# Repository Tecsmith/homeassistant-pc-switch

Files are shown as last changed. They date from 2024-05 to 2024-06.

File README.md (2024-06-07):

#  HA PC Switch

**Automate power on your PC using [ESPHome](https://github.com/esphome/esphome) or [Tasmota](https://github.com/arendst/Tasmota), and integrated into [Home Assistant](https://www.home-assistant.io/).**

## About

For more, visit the project page here: https://tecsmith.github.io/homeassistant-pc-switch/

## Assets:

* [Schematic PDF](docs/ha-pc-switch-revB.pdf)

---

Made with &#x1F499; by [](https://github.com/vinorodrigues).

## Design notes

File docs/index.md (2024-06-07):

#  HA PC Switch

**Automate power on your PC using [ESPHome](https://github.com/esphome/esphome) or [Tasmota](https://github.com/arendst/Tasmota), and integrated into [Home Assistant](https://www.home-assistant.io/).**

---

**`STATUS`**: This project is in ideation stage.  Come back soon for progress.

**`LAST UPDATE`**: 7 June 2024

---

## Origins

Looking for a way to remotely start-up and shut-down a PC from Home Assistant.  Also need operational status (sensors) to drive automations.

### June 2024 progress

In a case of [Multiple Discovery](https://en.wikipedia.org/wiki/multiple_discovery), it turns out that this idea already has commercial solutions for sale. I've found a few variants on AliExpress:

1. [Computer Remote Switch,Wifi Smart PC Start Boot Card,Startup Card Work with Apple Homekit SIRI](https://www.aliexpress.com/item/1005005378143852.html) - *This one I really like and have bought myself, as it's written specifically for the Apple Homekit eco-system that I use.I also like that it uses the new ESPC2-12 module.*

2. [TISHRIC Wifi PC Power Switch Computer Remote Boot Startup Card Computer Restart Switch Timing Boot Device Work With Alexa Google](https://www.aliexpress.com/item/1005004861684220.html) - *I really like the PCI bracket plate of this one. Depends on Tuya though* :( *.*

3. [eWeLink Computer Remote Boot Card Remote Control Wireless WIFI Switch Relay Module For Computer Work with Google Home and Alexa](https://www.aliexpress.com/item/1005001727371911.html) - *I think this one is one of the first modules developed.  Also relies on Tuya though* :( *.*

**However** - none of the above are open source - so we don't have the ability to modify the firmware ... and to add to that, most rely on the Tuya eco-system - so not viable for off-line use, and adds the "cloud" factor to it's use.

So I'm progressing with building ... EE design is done, but I need to change focus to building the firmware.

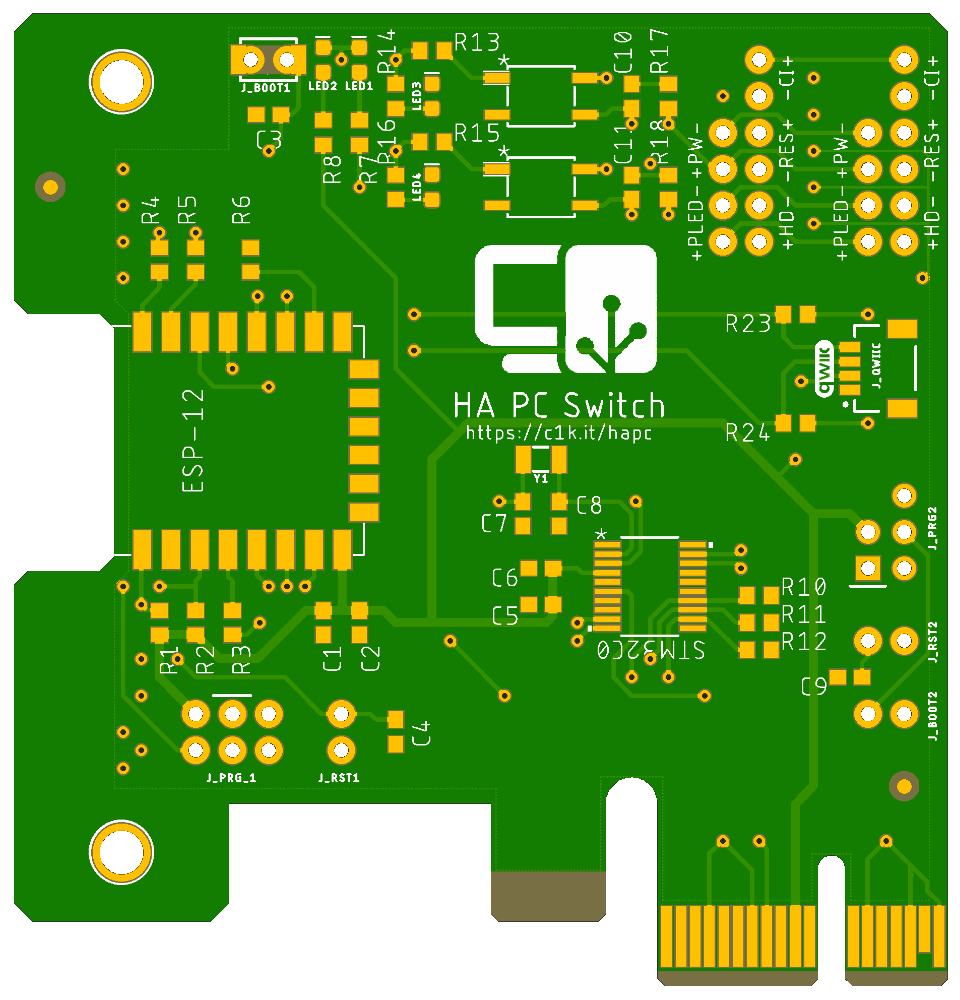
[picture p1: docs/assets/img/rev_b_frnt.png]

&nbsp;
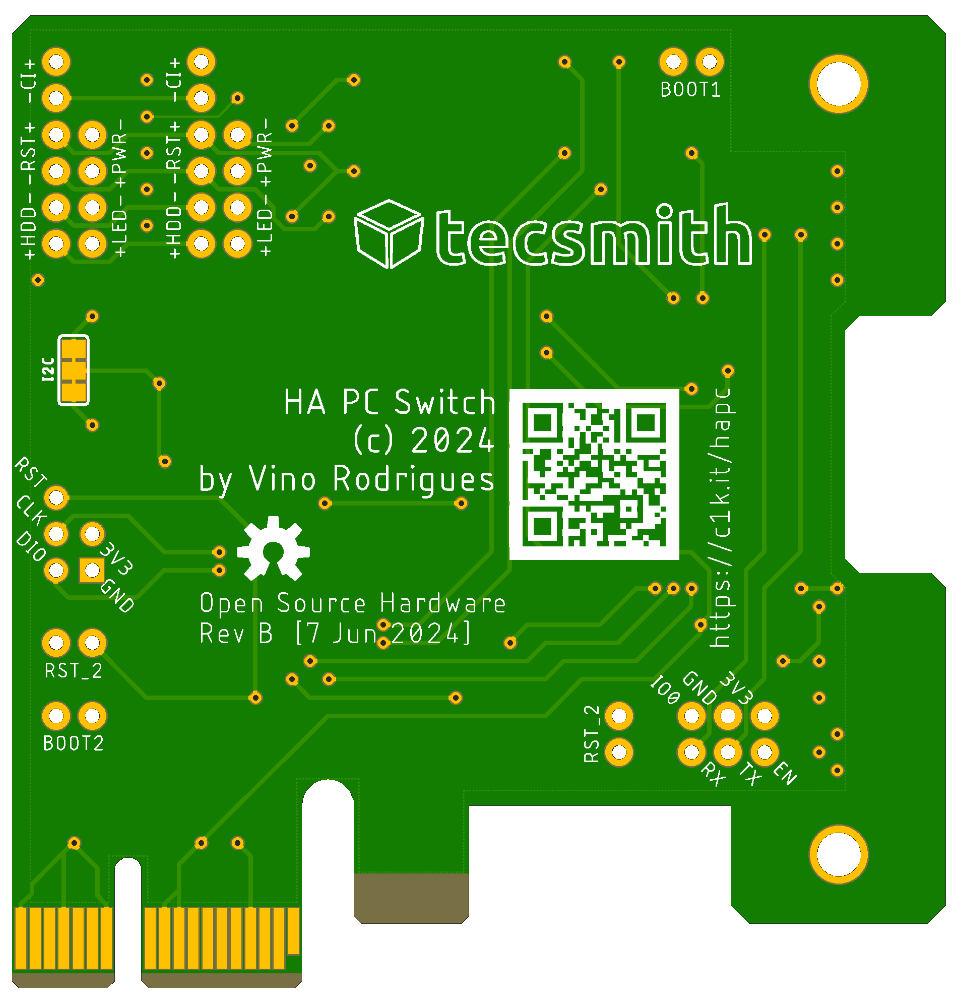
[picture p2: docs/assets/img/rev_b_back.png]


## Ideas

### Other People's Projects

* Zvonko Bockaj *@Hackster* - [WEMOS ESP8266 Remote PC Switch](https://www.hackster.io/zvonko-bockaj/wemos-esp8266-remote-pc-switch-062c7a) `// this one makes most sense`
* `ajfriesen` - [The pc-switch](https://www.ajfriesen.com/pc-switch/) `// great source for ESPHome YAML example`
* `Erriez` *@Github* - [ESPHomePCPowerControlHomeAssistant](https://github.com/Erriez/ESPHomePCPowerControlHomeAssistant/) `// ditto`

&

* `SilverFire` *@Github* - [esp8266-pc-power-control](https://github.com/SilverFire/esp8266-pc-power-control/)
* Lerk - [Turning a PC on and off using an ESP8266](https://lerks.blog/p/turning-a-pc-on-and-off-using-an-esp)

## Specifications (as a wish list)

### Inputs

1. ~~Power Standby (from PSU pin 9 {purple} / +5V SB (Standby)) - *as source of operating +5V power*~~
2. ~~Power Good (from PSU, pin 8 {grey} / PG (Pwr Good))~~
3. ~~Power Supply ON (from PSU, pins 21,22 {red} )~~
4. ~~PC ON (from Case LED)~~
5. ~~Case / MLB POWER Button~~
6. ~~Case / MLB Reset Button~~

* ~~GND (2x sources from PSU & MLB)~~

[June '24 update] - dropping the need for inputs.  Only one is needed at this stage .. i.e. is the PC ON or not.  Also removing the need for PSU monitoring, **and** it's source of power.  Turns out that PCIe bus supplies a 3.3V "Aux" line (a.k.a. "Standby" power), so we can just tap of the PCIe slot.

### Sensors (exposed to HA)

* ~~Power Good (from PSU, pin 8 {grey, *measure `true` when +5V*})~~
* ~~Power (Supply) ON (from PSU, pin 16 {green, *measure `false` when +5V* } / PS-ON (Pwr Sply switch))~~
    * ~~*This is the pin that need to be grounded for the PSU to switch on, so needs careful testing to make sure one does not have false ON states.*~~
* ~~(PC) Power ON (from MLB, case LED) {*measure `true` when +5V*}~~
* ~~Optional: via D1 Mini hats~~
    * ~~*(e.g. Case temperature)*~~
    * ~~expose D1 and D2 pins ...~~
    * ~~... or as I2C bus~~

### Outputs
* Power "relay" *(See note about "relay"'s in ideas below)*
* Reset "relay"
* ~~Case LED (as passthrough)~~
* ~~Optional: via D1 Mini hats~~
    ~~*(e.g. Contact Relay, as power to RGB LED's switch)*~~

[June '24 Update] - Solid state / MOSFET relays are still in.  Addon outputs are however dropped.  But... I2C is exposed as a single QWICC connector in case one wants to extend.

##### Terms used above
* **PSU** = Power Supply (Unit) <br/>
* **MLB** = Mail (Logic) Board / PC Motherboard 

## Ideas

* ~~"Sensor" should be isolated from circuit with an Op-amp Comparator](https://www.electronics-tutorials.ws/opamp/op-amp-comparator.html) or [Level Shifter](https://www.sparkfun.com/products/12009) circuit.  *(Inputs will be 5V, whilst the ESPxx works on 3.3v.)*~~

* "Relay" should be an [Optocoupler](https://www.electronics-tutorials.ws/blog/optocoupler.html)
    * ~~Do **<u>not</u>** use a transistor, nor a mechanical relay~~

    * Some PC's have "Positive" switches, others have "Negative" switches.  Accounting for this is too complex *(i.e. prone to installer error)*, so would it be better to use a ~~*relay* *(e.g. Omron G6K [SMD @ &#xB1;$7], or Songle `SRD-3VDC-SL-C` / Omrom G5LE [THD @ &#xB1;$0.36&#xA2;] )*~~.

        The issue here is that the MLB *(PC Motherboard)* may be using a low-sensing circuit, or a high-sensing circuit - and this PCB must account for both!

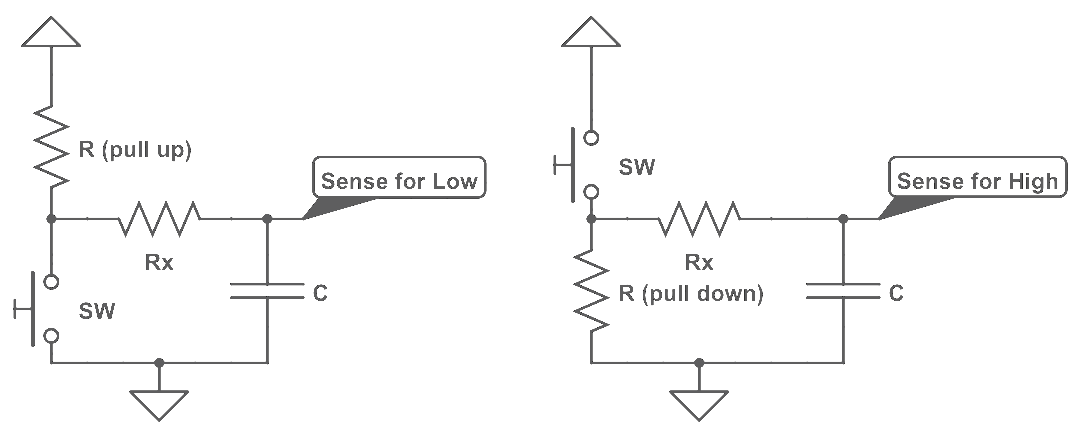
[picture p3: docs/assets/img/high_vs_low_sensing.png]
        <br/>

        All we get access to is the points that are the pins of the switch.

    * Solution looks to be a TIP3123 opto-MOSFET, thanks to [Andy aka](https://electronics.stackexchange.com/questions/548380/how-is-it-possible-to-replace-a-relay-with-transistors).

* &#x26A0; "Relay" should be driven by a "Delay OFF type" circuit, and 2 timings must be provided
    * 300ms delay from ON back to OFF to simulate a "press".
    * 5.5s delay on ON, then back to OFF to simulate a "long press".

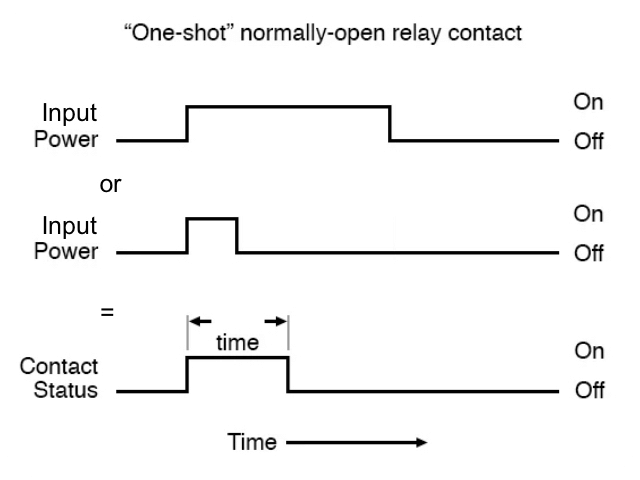
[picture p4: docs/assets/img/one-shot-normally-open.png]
        <br/>

    3 possible ways to do this:

    1. EE solution with caps and transistors - *not really viable since because of its variable performance and unchangeable nature. (See [here](https://www.homemade-circuits.com/simple-delay-timer-circuits-explained/))*

    2. If Software solution (i.e. on ESPHome or Tasmota), then how do we create a **"One-Shot" Normally-Open** switch?

        * ESPHome, can do this with with a [`on_turn_on` trigger](https://esphome.io/components/switch/gpio.html#momentary-switch).
        
        * Tasmota, can do this with "*Rules*" on the device.

        * Home Assistant with an automation trigger using an "`action`" > "`sequence`".

        But, what if the user forgets to "modify" the default f/w or build the HA automation required?  The device ***<u>must</u>*** handle the one-shot functionally itself.

        &#x26A0; Custom f/w (or fork of) must be built for timed "one-shot" / "delay off" functionality.

    3. Usa a second MCU with a timing circuit - e.g. ~~ATtiny85 or **STM8S001J3**~~ or **STM32C0**.

        * May be useful as a feedback "sensor".
        * Don't forget to provide programming headers.

* ~~Tap into the PSU ATX Cable for power and PSU inputs~~
    * ~~Std ATX~~ <br/>
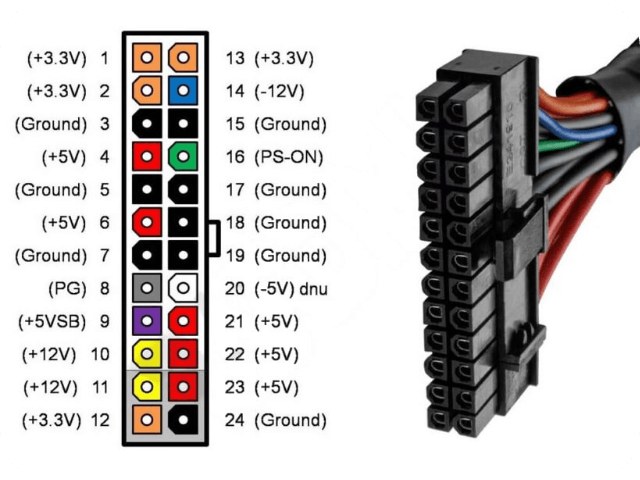
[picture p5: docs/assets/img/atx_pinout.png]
        
    * ~~Use a ATX power extender to "tap" into correct cables~~ <br/>
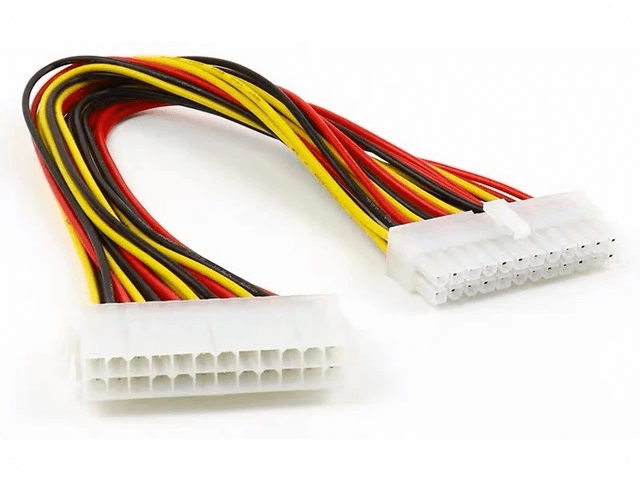
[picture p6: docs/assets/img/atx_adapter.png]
        

* ~~Use the WEMOS D1 Mini form-factor and pin-outs, but prototype on:~~
    * ~~[WEMOS D1 Mini Pro](https://www.aliexpress.com/item/1005006109635545.html) (with external antenna) <br/>~~
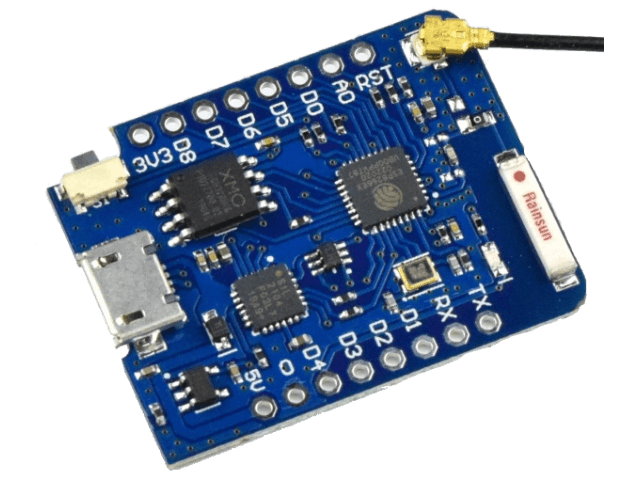
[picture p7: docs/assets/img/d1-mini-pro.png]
      
    * ~~[LOLIN ESP32 S2 Mini](https://www.aliexpress.com/item/1005006157693055.html)~~ <br/>
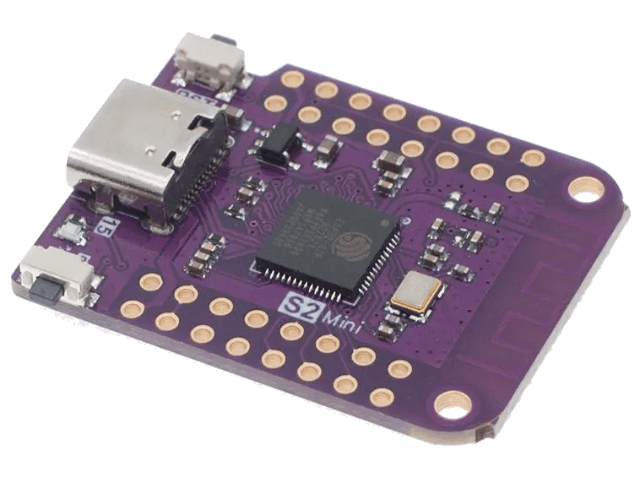
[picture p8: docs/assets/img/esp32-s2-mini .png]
      

* [May '24 Update] ~~Also add a~~ footprint for the **ESP-12F**/ESP-12S module
    * Cheaper, but needs external programmer (add headers for that).

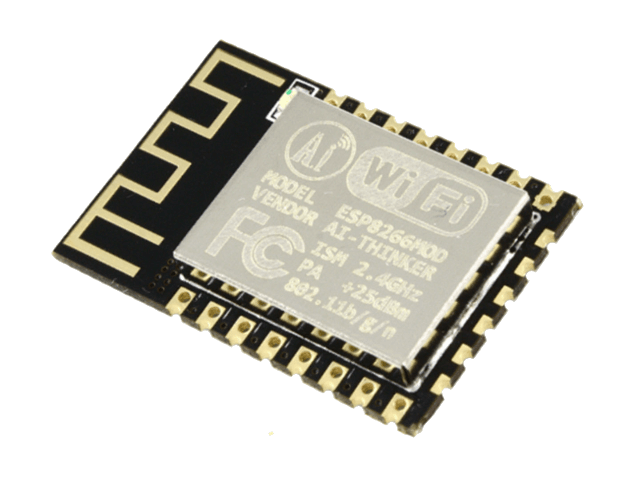
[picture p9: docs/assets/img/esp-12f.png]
      

    * [Update '24 Update] Both the **ESP-07** and the newer **ESPC2-12** modules have the same footprint and pinout, adding far more versatility.

* ~~Build the PCB in a way that the unit can attach to a **PCI Slot Bracket Cover**, specifically build for:~~
    * ~~PCI Slot Fan Mount Rack for video card for 90mm and 120mm fans~~ <br/>
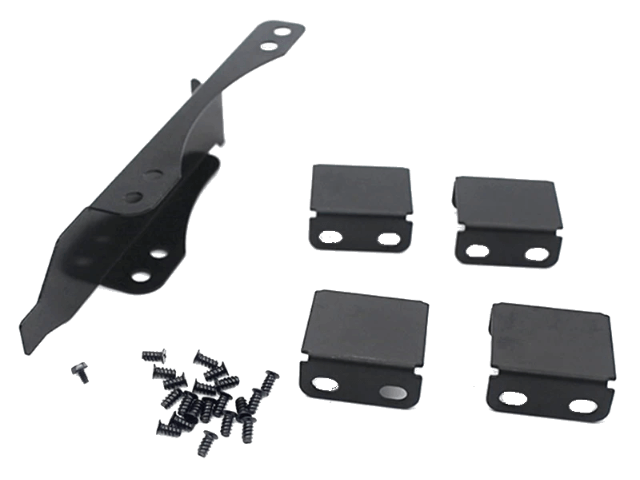
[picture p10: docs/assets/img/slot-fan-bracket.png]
      
    * ~~PCI Slot for 2.5inch hard drive, rear panel mount~~ <br/>
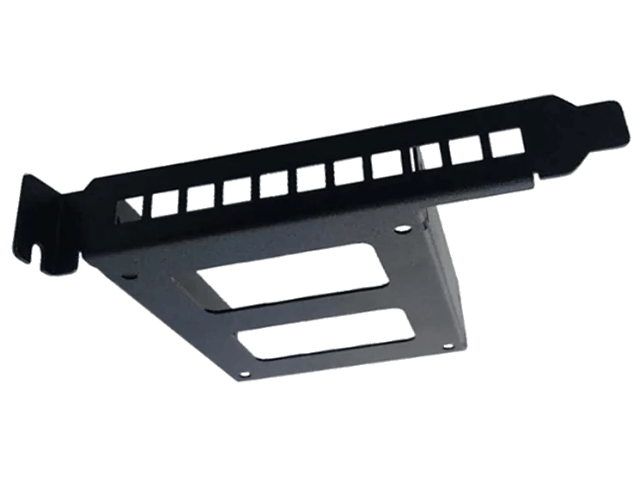
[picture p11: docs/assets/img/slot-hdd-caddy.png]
      

    Will allow for drilling holes for external antenna.

* [June '24 Update] Build to [PCIe V2 specification](specs/pci-express-card-electromechanical-specification-revision-2.pdf).  To fit standard PCI Bracket plates:
  
  * [Example 1](https://www.aliexpress.com/item/1005005341638856.html)
  * [Example 2](https://www.aliexpress.com/item/1005004003916975.html)

---

Made with &#x1F499; by [](https://github.com/vinorodrigues).

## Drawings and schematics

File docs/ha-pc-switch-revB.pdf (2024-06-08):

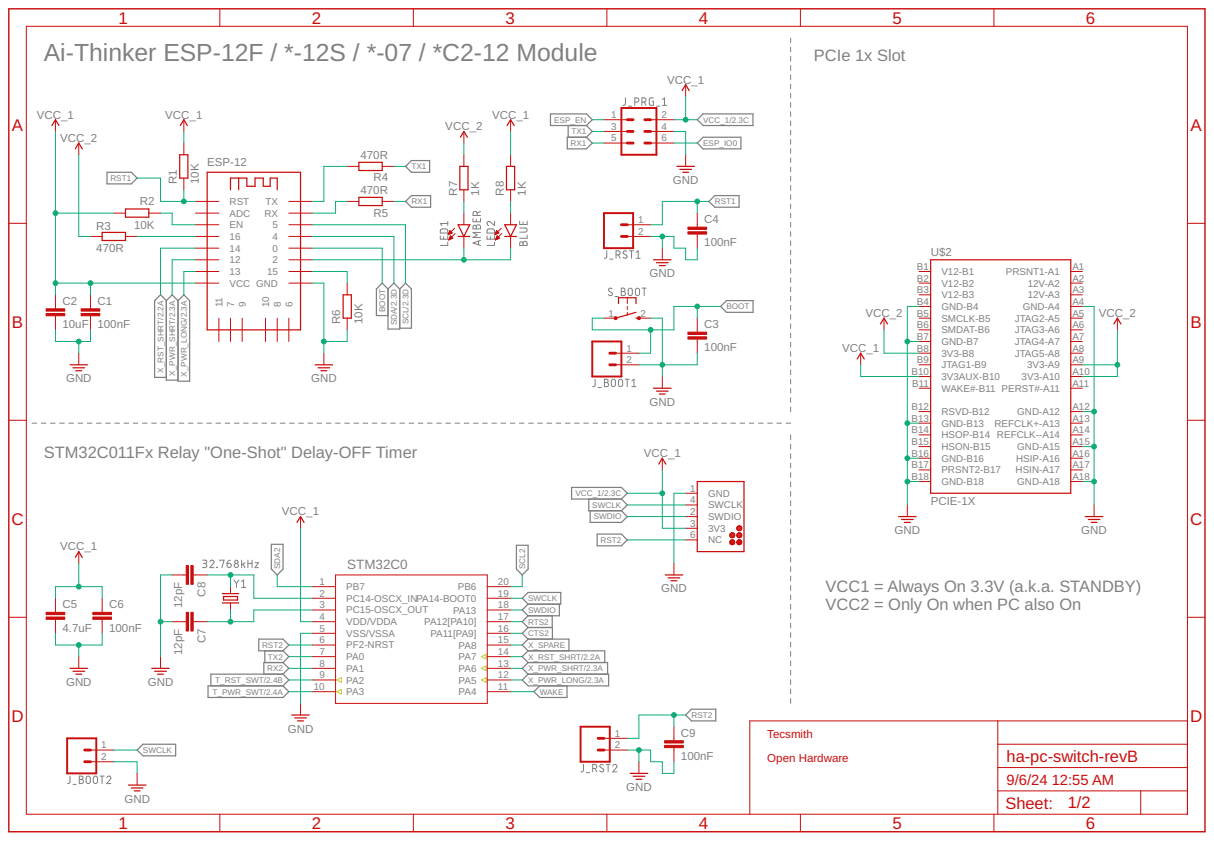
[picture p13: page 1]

Ai-Thinker ESP-12F / *-12S / *-07 / *C2-12 Module

STM32C011Fx Relay "One-Shot" Delay-OFF Timer

VCC1 = Always On 3.3V (a.k.a. STANDBY)
VCC2 = Only On when PC also On

2 | | 19 PB6
3 | | 18 PA14-BOOT0
4 | | 15 PA11[PA9] 16 PA12[PA10] 17 PA13

7 | 14 PA8
8 | 13 PA7
9 | 12 PA6

ha-pc-switch-revB
Sheet:

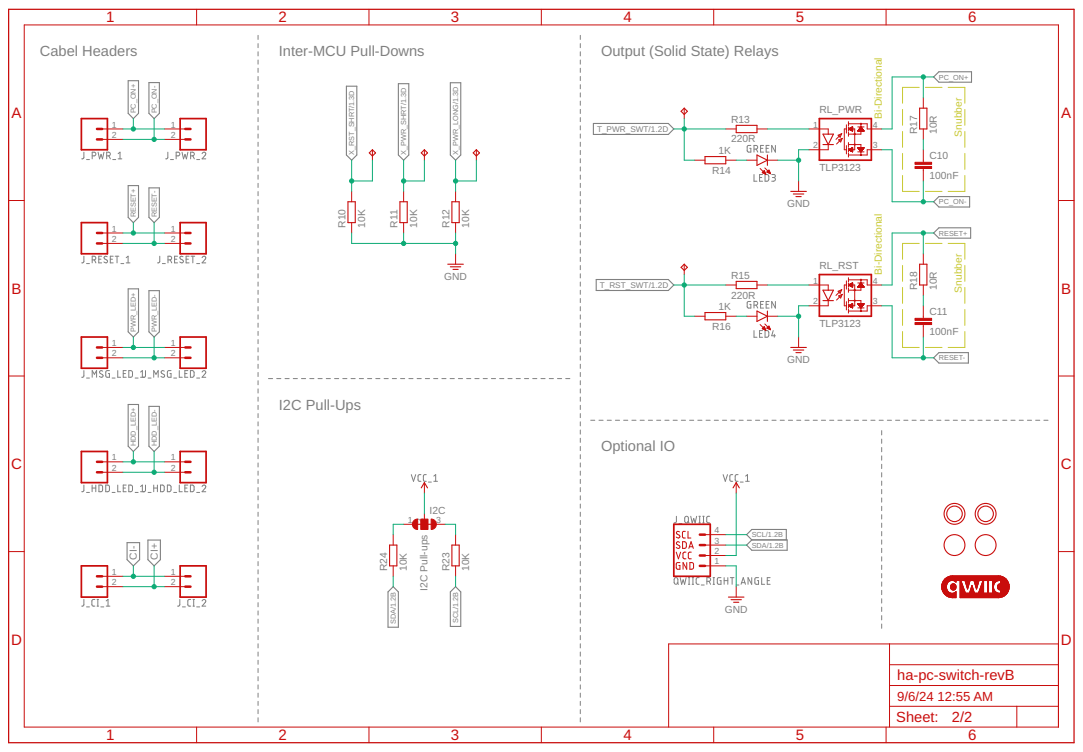
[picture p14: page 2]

Snubber Snubber Bi-Directional Bi-Directiona Cabe l l Headers Output (Solid State) Relays Optional IO I2C Pull-ups Inter-MCU Pull-Downs I2C Pull-Ups 100nF 10R 220R GND 100nF 10R 220R GND GND TLP3123 TLP3123 1K1K 10K 10K 10K 10K 10K GND 12121212 12121212 12 12 C10 R1R13 7 C11 R1R15 8 1234 12 34 RL_PWR 12 34 RL_RST R14 R16 1 23 I2C R23 R24 R11 R12 R10 PWR_LED+ RESET+ RESET+ PC_ON+ PC_ON+ HDD_LED+ PWR_LED- HDD_LED- PC_ON- PC_ON- RESET- RESET- CI- CI+ T_PWR_SWT/1.2D T_RST_SWT/1.2D SCL/1.2B SCL/1.2B SDA/1.2B SDA/1.2B X_PWR_SHRT/1.3D X_PWR_LONG/1.3D X_RST_SHRT/1.3D Sheet: ABCD 1 2 3 4 5 6 ABCD 1 2 3 4 5 6 ha-pc-switch-revB 9/6/24 12:55 AM 2/2

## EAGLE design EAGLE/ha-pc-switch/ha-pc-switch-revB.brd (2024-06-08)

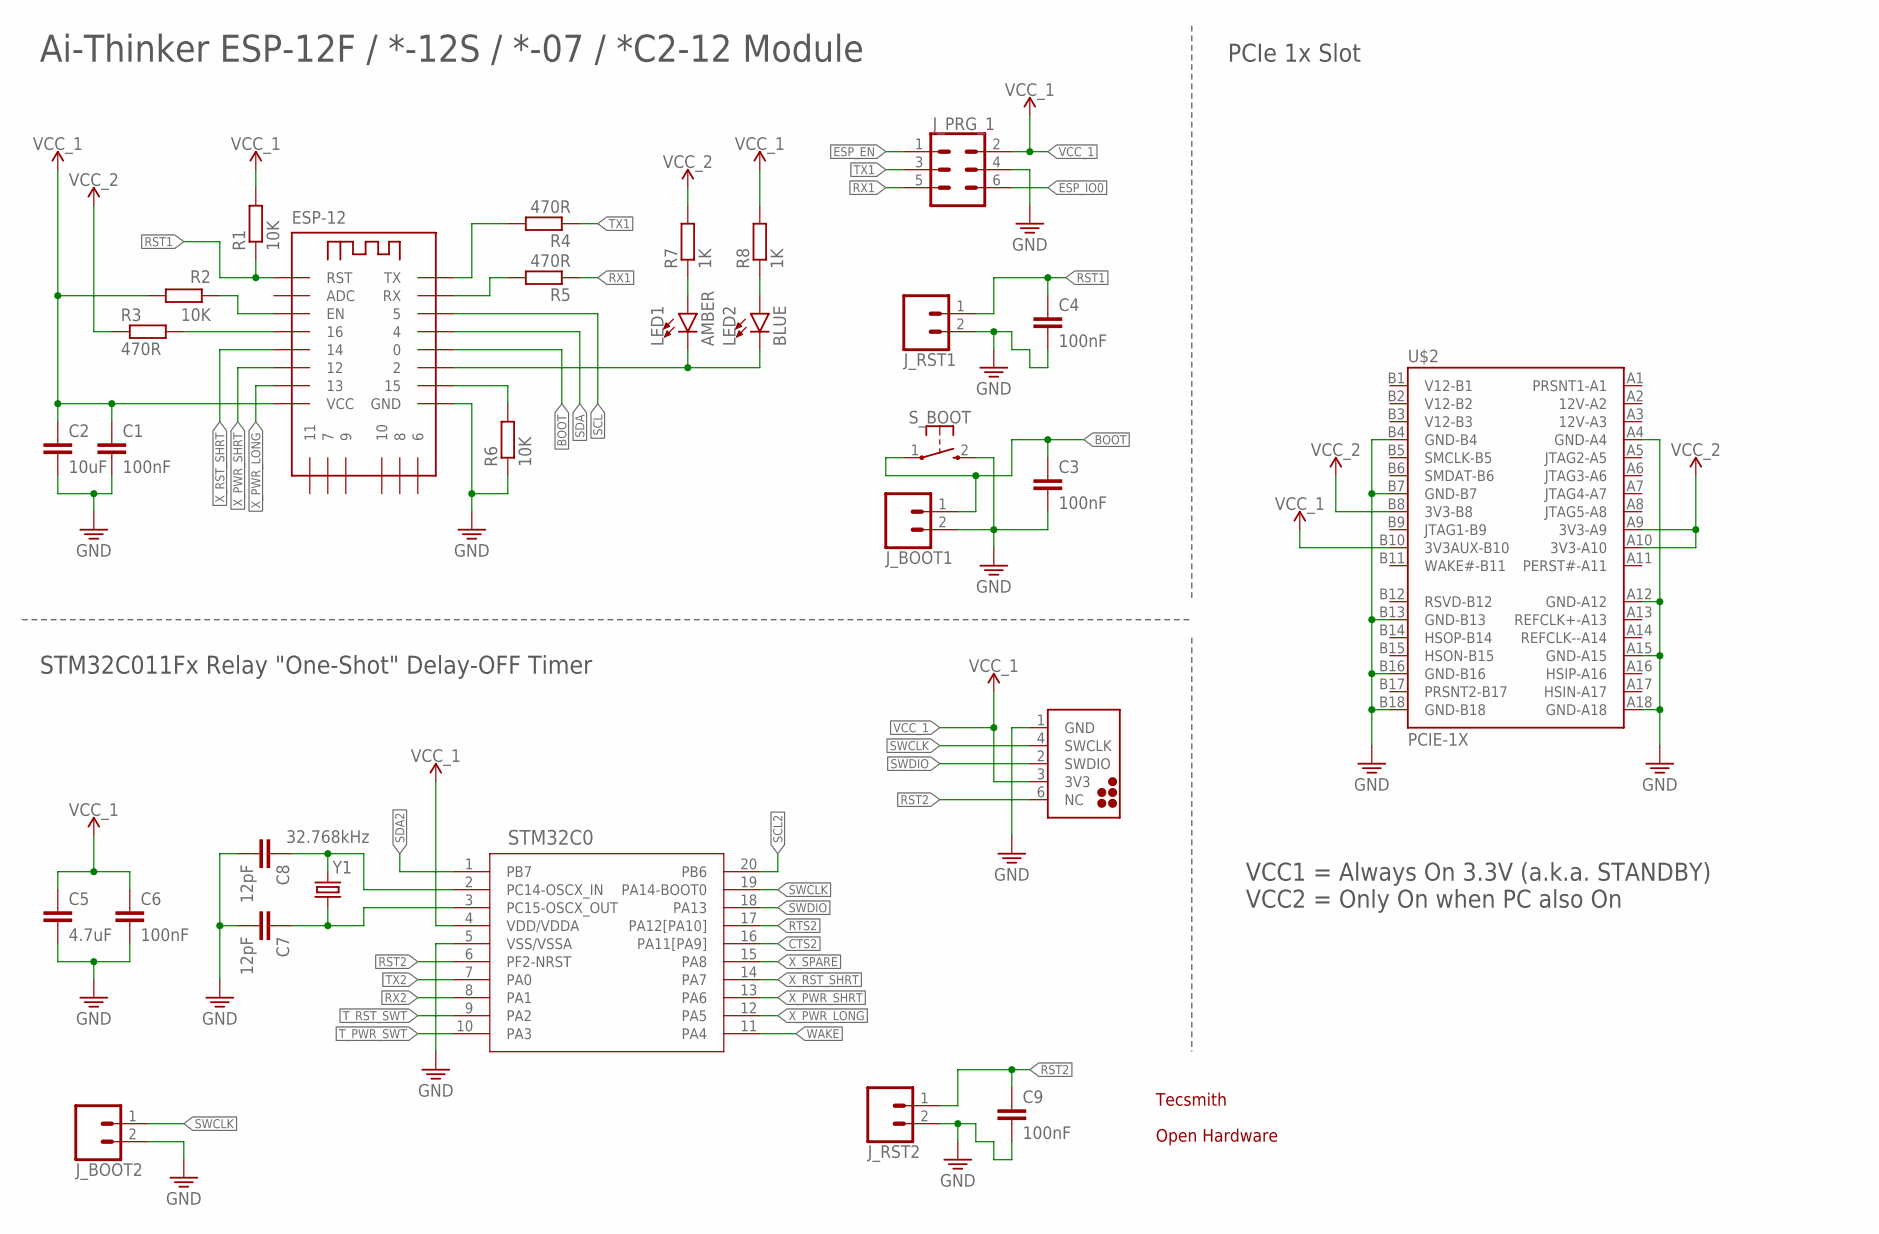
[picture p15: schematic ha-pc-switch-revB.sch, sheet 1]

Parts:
C1, C3, C4, C6, C9: 100nF; C0603
C2: 10uF; C0603
C5: 4.7uF; C0603
C7, C8: 12pF; C0603
ESP-12: ESPRESSIF-ESP-12F&ESMD; ESP8266-ESP-12E
J_BOOT1, J_BOOT2: CONN_021X02_NO_SILK; 1X02_NO_SILK
J_PRG2: NUCLEO_HEADER; NUCLEO
J_PRG_1: CONN_03X2NO_SILK; 2X3-NS
J_RST1, J_RST2: CONN_021X02_NO_SILK; 1X02_NO_SILK
LED1: AMBER; LED-0603
LED2: BLUE; LED-0603
LOGO1: OSHW-LOGOM; OSHW-LOGO-M
R1, R2, R6: 10K; R0603
R3, R4, R5: 470R; R0603
R7, R8: 1K; R0603
STM32C0: STM32C011FTSSOP20_STM-M; TSSOP20-M
S_BOOT: MOMENTARY-SWITCH-SPST-1; SKRKAEE020
U$1: TECSMITH-LOGOLONG; TECSMITH-NAME
U$2: PCIE-1X
Y1: 32.768kHz; CRYSTAL-SMD-3.2X1.5MM

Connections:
BOOT: C3.1, ESP-12.GPIO0 (0), J_BOOT1.1, S_BOOT.1
CTS2: STM32C0.16 (PA11[PA9])
ESP_EN: ESP-12.EN, J_PRG_1.1, R2.2
ESP_IO0: J_PRG_1.6
GND: C1.2, C2.2, C3.2, C4.2, C5.2, C6.2, C7.2, C8.2, C9.2, ESP-12.GND, J_BOOT1.2, J_BOOT2.2, J_PRG2.1 (GND), J_PRG_1.4, J_RST1.2, J_RST2.2, R6.1, STM32C0.5 (VSS/VSSA), S_BOOT.2 (3), U$2.A4 (GND-A4), U$2.A12 (GND-A12), U$2.A15 (GND-A15), U$2.A18 (GND-A18), U$2.B4 (GND-B4), U$2.B7 (GND-B7), U$2.B13 (GND-B13), U$2.B16 (GND-B16), U$2.B18 (GND-B18); also elsewhere on the board
unnamed: ESP-12.GPIO16 (16), R3.2
unnamed: LED2.A, R8.1
unnamed: C8.1, STM32C0.2 (PC14-OSCX_IN), Y1.P$2 (2)
unnamed: C7.1, STM32C0.3 (PC15-OSCX_OUT), Y1.P$1 (1)
unnamed: LED1.A, R7.1
unnamed: ESP-12.RXD0 (RX), R5.2
unnamed: ESP-12.GPIO2 (2), LED1.C, LED2.C
unnamed: ESP-12.TXD0 (TX), R4.2
unnamed: ESP-12.GPIO15 (15), R6.2
RST1: C4.1, ESP-12.RST, J_RST1.1, R1.1
RST2: C9.1, J_PRG2.6 (NC), J_RST2.1, STM32C0.6 (PF2-NRST)
RTS2: STM32C0.17 (PA12[PA10])
RX1: J_PRG_1.5, R5.1
RX2: STM32C0.8 (PA1)
SCL: ESP-12.GPIO5 (5); also elsewhere on the board
SCL2: STM32C0.20 (PB6)
SDA: ESP-12.GPIO4 (4); also elsewhere on the board
SDA2: STM32C0.1 (PB7)
SWCLK: J_BOOT2.1, J_PRG2.4 (SWCLK), STM32C0.19 (PA14-BOOT0)
SWDIO: J_PRG2.2 (SWDIO), STM32C0.18 (PA13)
TX1: J_PRG_1.3, R4.1
TX2: STM32C0.7 (PA0)
T_PWR_SWT: STM32C0.10 (PA3); also elsewhere on the board
T_RST_SWT: STM32C0.9 (PA2); also elsewhere on the board
VCC_1: C1.1, C2.1, C5.1, C6.1, ESP-12.VCC, J_PRG2.3 (3V3), J_PRG_1.2, R1.2, R2.1, R8.2, STM32C0.4 (VDD/VDDA), U$2.B10 (3V3AUX-B10); also elsewhere on the board
VCC_2: R3.1, R7.2, U$2.A9 (3V3-A9), U$2.A10 (3V3-A10), U$2.B8 (3V3-B8)
WAKE: STM32C0.11 (PA4)
X_PWR_LONG: ESP-12.GPIO13 (13), STM32C0.12 (PA5); also elsewhere on the board
X_PWR_SHRT: ESP-12.GPIO12 (12), STM32C0.13 (PA6); also elsewhere on the board
X_RST_SHRT: ESP-12.GPIO14 (14), STM32C0.14 (PA7); also elsewhere on the board
X_SPARE: STM32C0.15 (PA8)

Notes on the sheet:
Ai-Thinker ESP-12F / *-12S / *-07 / *C2-12 Module
STM32C011Fx Relay "One-Shot" Delay-OFF Timer
VCC1 = Always On 3.3V (a.k.a. STANDBY) VCC2 = Only On when PC also On
PCIe 1x Slot

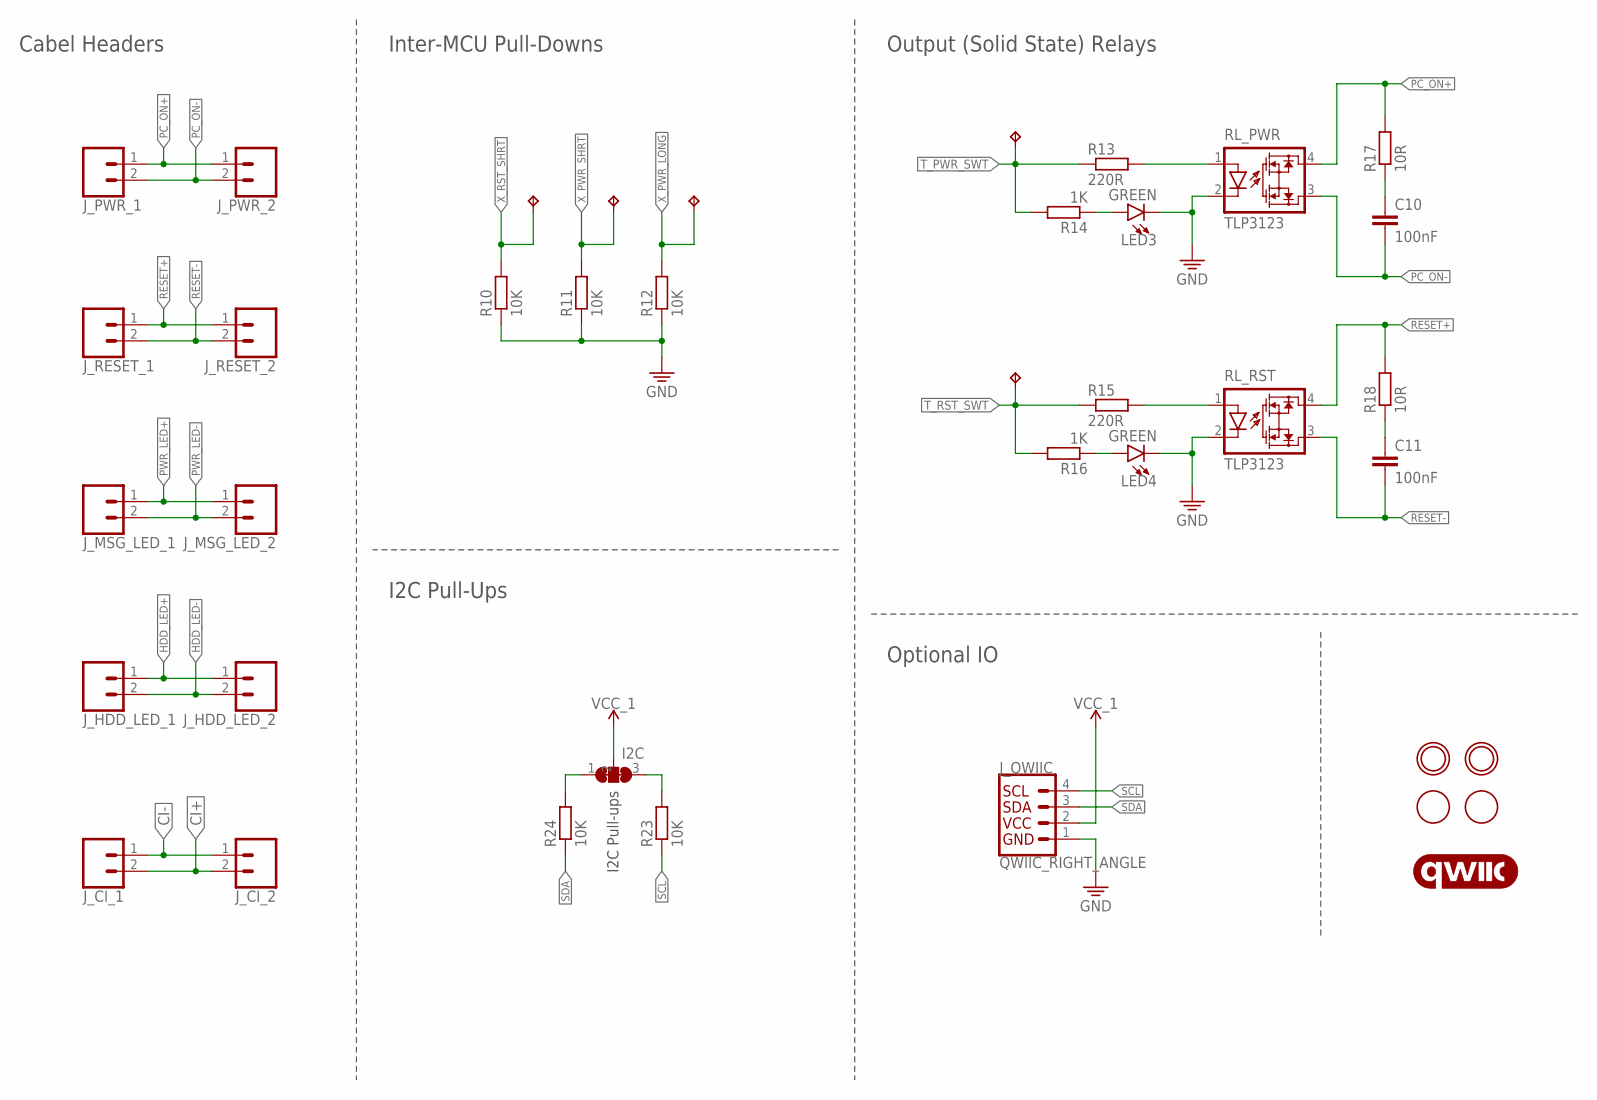
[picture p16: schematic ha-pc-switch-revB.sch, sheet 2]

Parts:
C10, C11: 100nF; C0603
I2C: JUMPER-1X3-CLOSED-2; SOLDERJUMPER_CLOSEDWIRE-3-2
J_CI_1, J_CI_2: CONN_021X02_NO_SILK; 1X02_NO_SILK
J_HDD_LED_1, J_HDD_LED_2: CONN_021X02_NO_SILK; 1X02_NO_SILK
J_MSG_LED_1, J_MSG_LED_2: CONN_021X02_NO_SILK; 1X02_NO_SILK
J_PWR_1, J_PWR_2: CONN_021X02_NO_SILK; 1X02_NO_SILK
J_QWIIC: QWIIC_RIGHT_ANGLE; JST04_1MM_RA
J_RESET_1, J_RESET_2: CONN_021X02_NO_SILK; 1X02_NO_SILK
LED3, LED4: GREEN; LED-0603
LOGO2: QWIIC_LOGO_4MM; QWIIC_4MM
R10, R11, R12, R23, R24: 10K; R0603
R13, R15: 220R; R0603
R14, R16: 1K; R0603
R17, R18: 10R; R0603
RL_PWR: TLP3123; SOP4_TOS
RL_RST: TLP3123; SOP4_TOS
TP6, TP7, TP8, TP9, TP10: TPTP16SQ; TP16SQ
U$9, U$11: MOUNTINGHOLE3.0THIN; MOUNTINGHOLE_3.0_PLATEDTHIN
U$15, U$16: FIDUCIAL; FIDUCIAL_1MM

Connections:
CI+: J_CI_1.2, J_CI_2.2
CI-: J_CI_1.1, J_CI_2.1
GND: J_QWIIC.1, LED3.C, LED4.C, R10.1, R11.1, R12.1, RL_PWR.2 (C), RL_RST.2 (C); also elsewhere on the board
HDD_LED+: J_HDD_LED_1.1, J_HDD_LED_2.1
HDD_LED-: J_HDD_LED_1.2, J_HDD_LED_2.2
unnamed: R15.2, RL_RST.1 (A)
unnamed: C10.1, R17.1
unnamed: C11.1, R18.1
unnamed: R13.2, RL_PWR.1 (A)
unnamed: LED3.A, R14.1
unnamed: I2C.3, R23.2
unnamed: I2C.1, R24.2
unnamed: LED4.A, R16.1
PC_ON+: J_PWR_1.1, J_PWR_2.1, R17.2, RL_PWR.4 (D1)
PC_ON-: C10.2, J_PWR_1.2, J_PWR_2.2, RL_PWR.3 (D2)
PWR_LED+: J_MSG_LED_1.1, J_MSG_LED_2.1
PWR_LED-: J_MSG_LED_1.2, J_MSG_LED_2.2
RESET+: J_RESET_1.1, J_RESET_2.1, R18.2, RL_RST.4 (D1)
RESET-: C11.2, J_RESET_1.2, J_RESET_2.2, RL_RST.3 (D2)
SCL: J_QWIIC.4, R23.1; also elsewhere on the board
SDA: J_QWIIC.3, R24.1; also elsewhere on the board
T_PWR_SWT: R13.1, R14.2, TP9.TP; also elsewhere on the board
T_RST_SWT: R15.1, R16.2, TP10.TP; also elsewhere on the board
VCC_1: I2C.2, J_QWIIC.2; also elsewhere on the board
X_PWR_LONG: R12.2, TP8.TP; also elsewhere on the board
X_PWR_SHRT: R11.2, TP7.TP; also elsewhere on the board
X_RST_SHRT: R10.2, TP6.TP; also elsewhere on the board

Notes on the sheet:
Cabel Headers
Output (Solid State) Relays
Optional IO
I2C Pull-ups
Inter-MCU Pull-Downs
I2C Pull-Ups

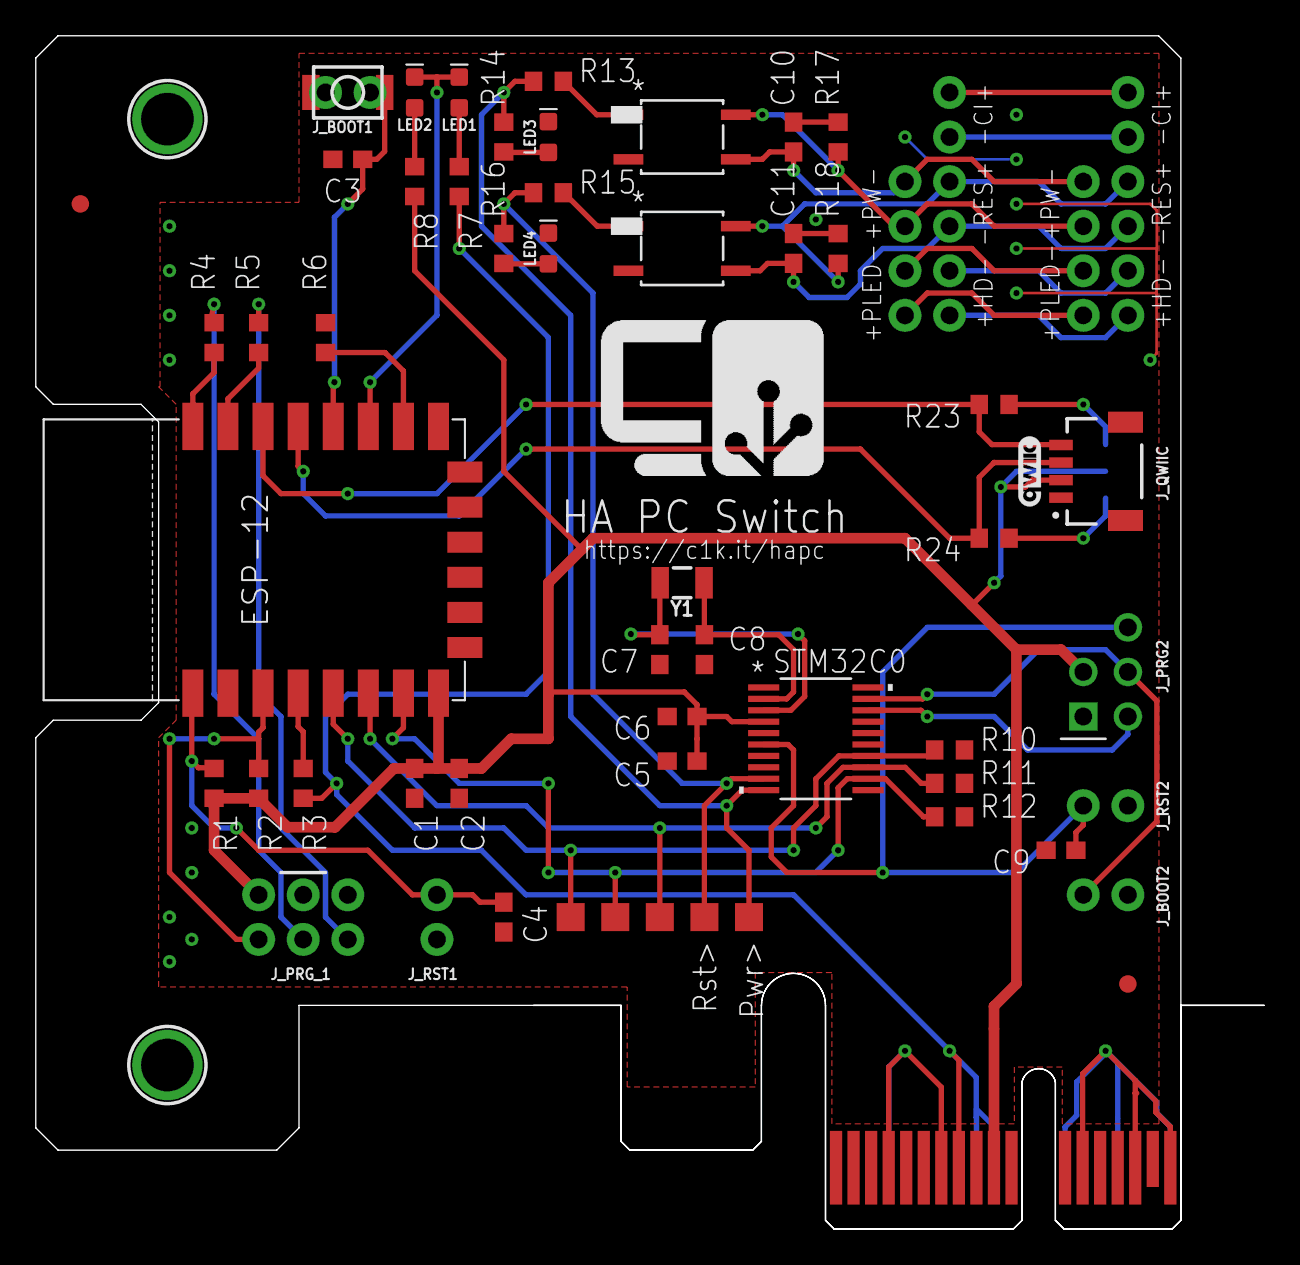
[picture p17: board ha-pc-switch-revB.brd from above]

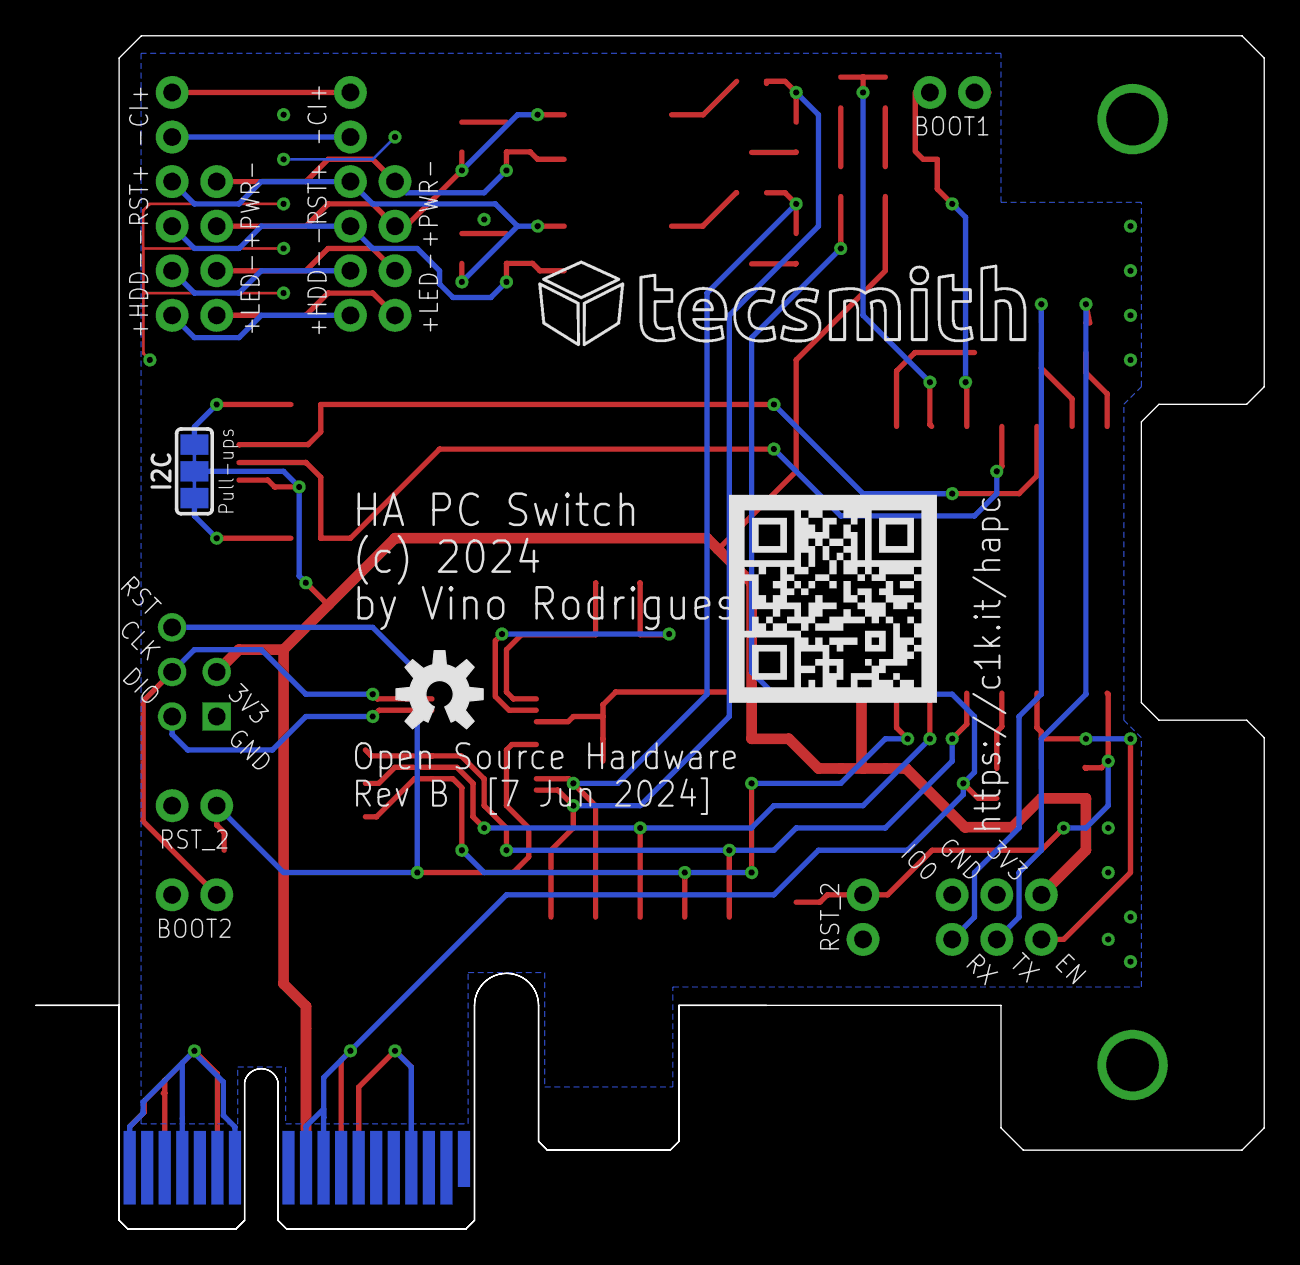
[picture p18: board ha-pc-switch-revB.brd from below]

Board: 2 copper layers, 70.0 x 68.0 mm, 71 parts (3 on the bottom side), 45 nets.

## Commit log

2024-05-05 EAGLE sch's
    [ha-pc-switch-revA.brd, ha-pc-switch-revA.sch]
2024-06-02 pcb routed
    [ha-pc-switch-revA.brd, ha-pc-switch-revA.sch]
2024-06-07 Rev B
    [ha-pc-switch-revA.brd, ha-pc-switch-revB.brd, ha-pc-switch-revB.sch]

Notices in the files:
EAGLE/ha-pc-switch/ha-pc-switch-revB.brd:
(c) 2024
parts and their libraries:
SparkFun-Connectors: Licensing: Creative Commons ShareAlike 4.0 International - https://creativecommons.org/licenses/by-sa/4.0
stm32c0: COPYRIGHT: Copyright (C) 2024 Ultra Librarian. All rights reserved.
